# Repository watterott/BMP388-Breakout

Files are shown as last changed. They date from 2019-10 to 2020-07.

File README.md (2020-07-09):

# BMP388-Breakout
Breakout with BMP388 Digital Absolute Barometric Pressure Sensor from Bosch Sensortec.

* [Bosch BMP388](https://www.bosch-sensortec.com/bst/products/all_products/BMP388) Absolute Barometric Pressure Sensor
* Pressure Range: 300...1100hPa (+9000...-500m above/below sea level)
* On-board 3.3V voltage regulator
* SPI Interface (up to 10MHz)
* TWI/I2C Interface (address 0x76 when SDO=0 or 0x77 when SDO=1, CS=1 for I2C)
* 3.3V - 5V Power Supply and Logic Level
* Open-Source and released under the [Creative Commons Attribution Share-Alike License](https://creativecommons.org/licenses/by-sa/4.0/).
* **[Documentation on learn.watterott.com](https://learn.watterott.com)**

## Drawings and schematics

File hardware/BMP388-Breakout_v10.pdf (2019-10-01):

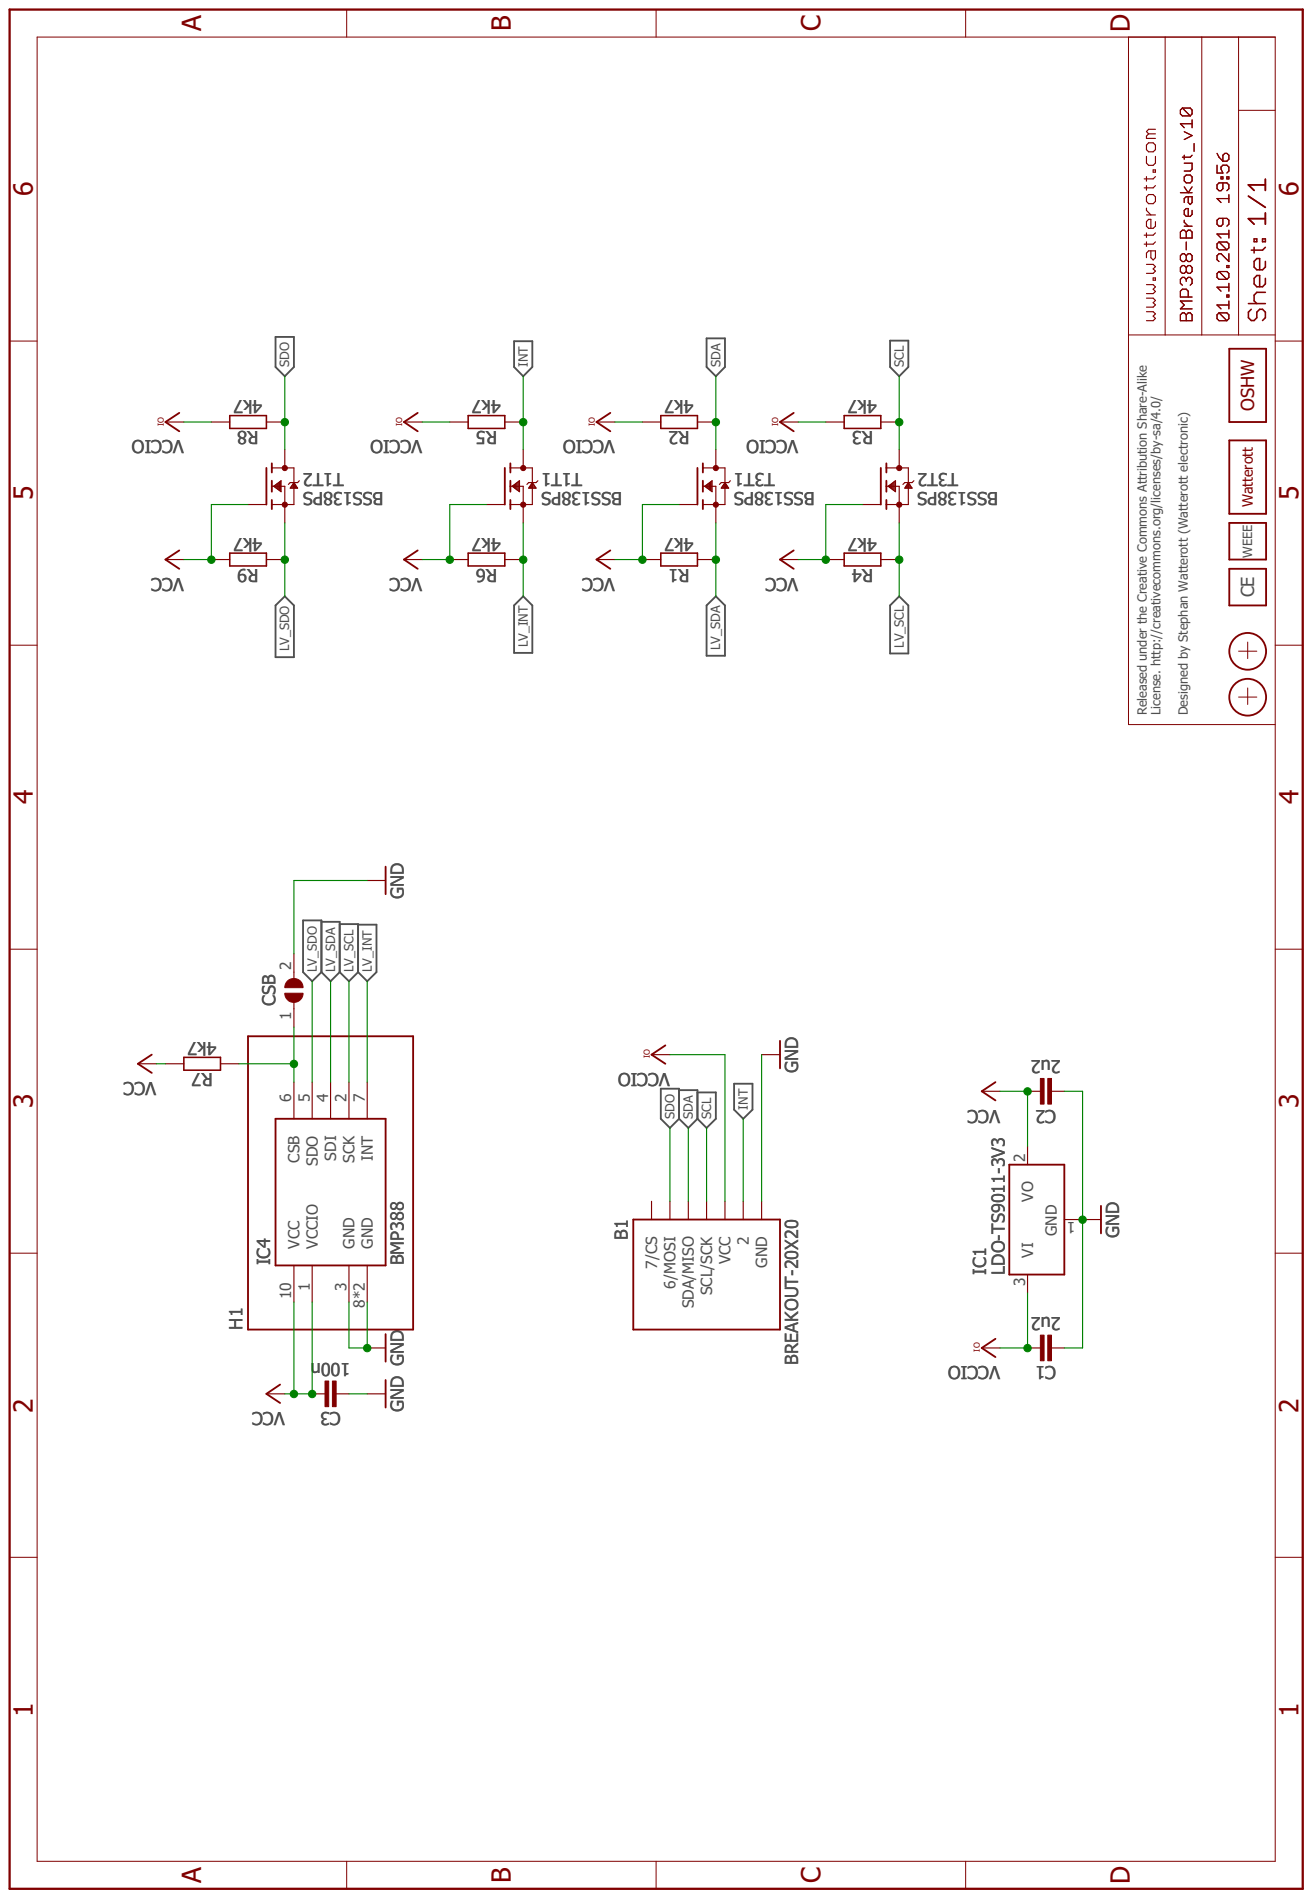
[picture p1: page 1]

Released under the Creative Commons Attribution Share-Alike

License. http://creativecommons.org/licenses/by-sa/4.0/ Designed by Stephan Watterott (Watterott electronic)

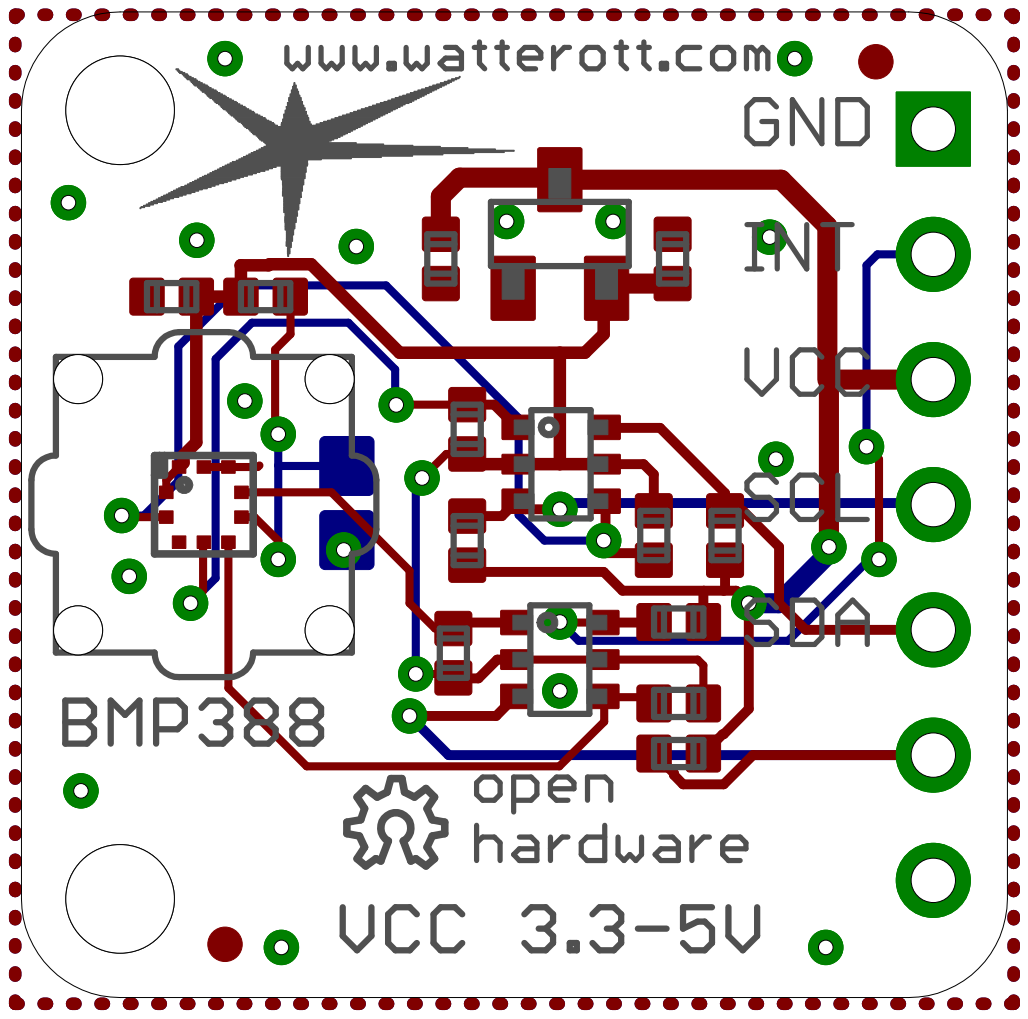
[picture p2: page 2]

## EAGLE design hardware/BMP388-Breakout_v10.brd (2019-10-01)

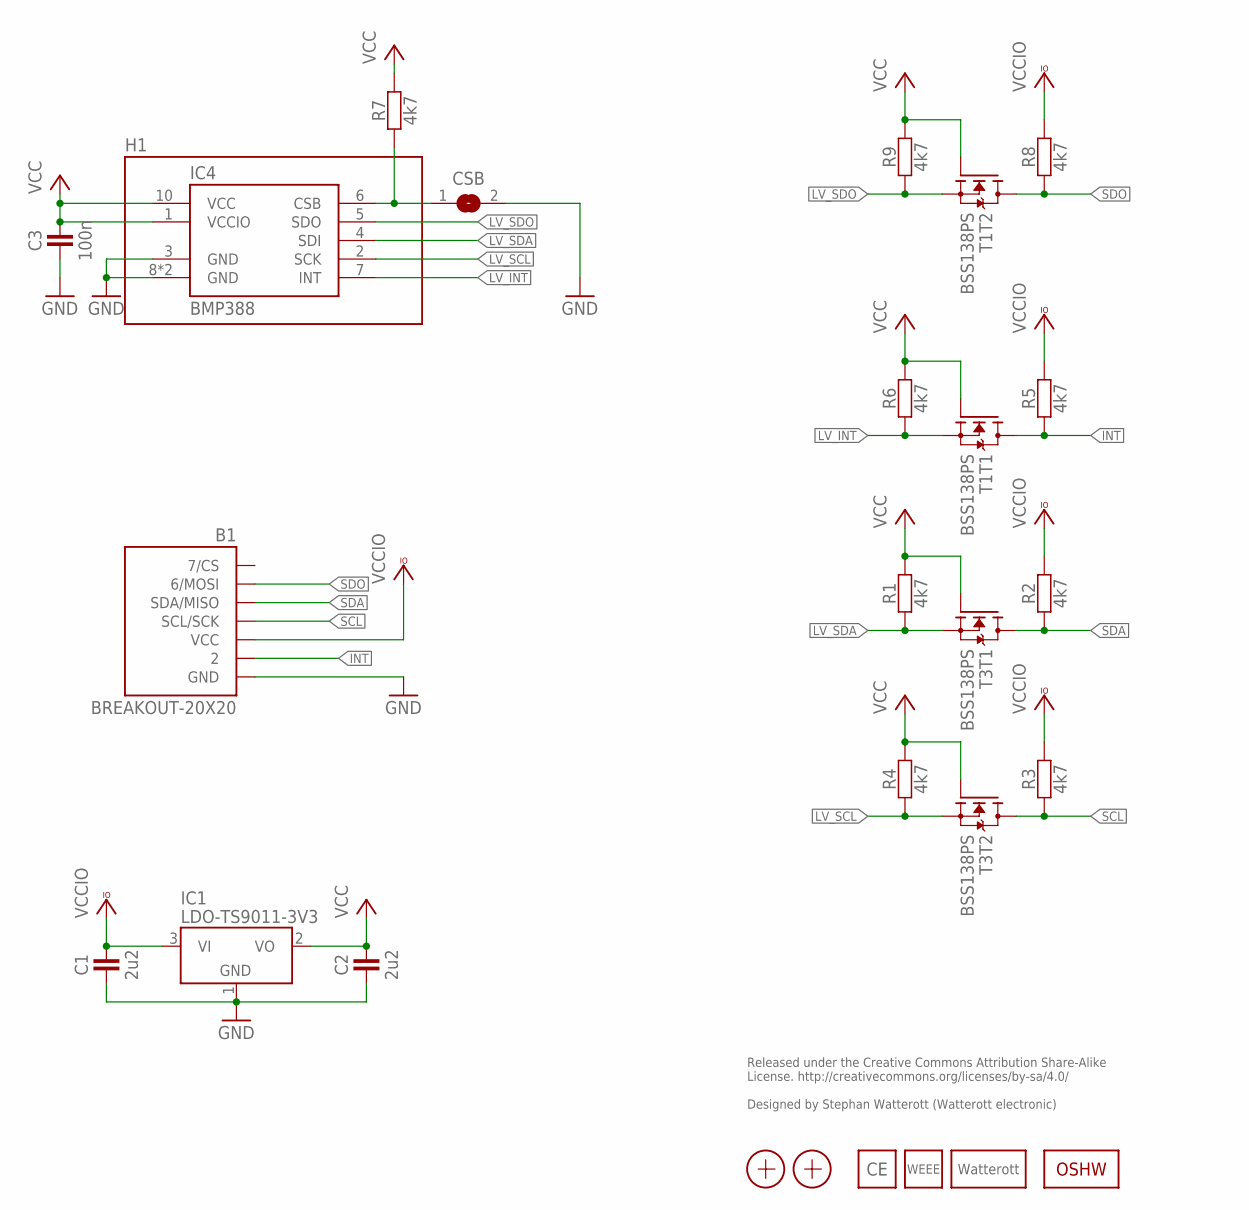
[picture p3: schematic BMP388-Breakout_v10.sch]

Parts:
B1: BREAKOUT-20X20
C1, C2: 2u2; C0402
C3: 100n; C0402
CSB: JUMPER2-0603-NC; JUMPER2-0603_NC
H1: SF2
IC1: LDO-TS9011-3V3; SOT23
IC4: BMP388
LOGO2: OSHW_LOGOX0070; OSHW_6X70
LOGO3: LOGO_WEEE-4; WEEE_4MM
LOGO4: LOGO_CE-4; CE_4MM
LOGO5: LOGO_SPARK-4; SPARK_4MM
R1, R2, R3, R4, R5, R6, R7, R8, R9: 4k7; C0402
T1, T3: BSS138PS; SOT363
X1, X2: PASSER-07; PASSER_07MM

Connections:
GND: B1.GND, C1.1, C2.1, C3.1, CSB.2, IC1.1 (GND), IC4.3 (GND), IC4.8 (GND), IC4.9 (GND)
INT: B1.2, R5.1, T1.6 (D)
LV_INT: IC4.7 (INT), R6.1, T1.1 (S)
LV_SCL: IC4.2 (SCK), R4.1, T3.4 (S)
LV_SDA: IC4.4 (SDI), R1.1, T3.1 (S)
LV_SDO: IC4.5 (SDO), R9.1, T1.4 (S)
unnamed: CSB.1, IC4.6 (CSB), R7.1
SCL: B1.SCL/SCK, R3.1, T3.3 (D)
SDA: B1.SDA/MISO, R2.1, T3.6 (D)
SDO: B1.MOSI (6/MOSI), R8.1, T1.3 (D)
VCC: C2.2, C3.2, IC1.2 (VO), IC4.1 (VCCIO), IC4.10 (VCC), R1.2, R4.2, R6.2, R7.2, R9.2, T1.2 (G), T1.5 (G), T3.2 (G), T3.5 (G)
VCCIO: B1.VCC, C1.2, IC1.3 (VI), R2.2, R3.2, R5.2, R8.2

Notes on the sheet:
Released under the Creative Commons Attribution Share-Alike License. http://creativecommons.org/licenses/by-sa/4.0/ Designed by Stephan Watterott (Watterott electronic)

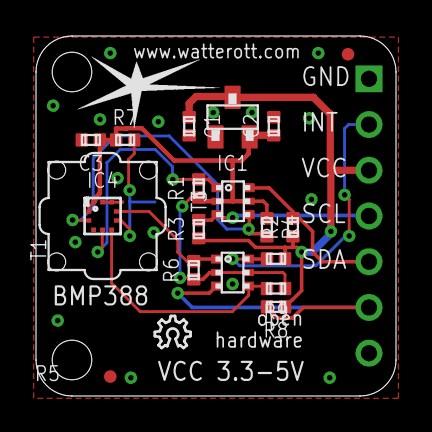
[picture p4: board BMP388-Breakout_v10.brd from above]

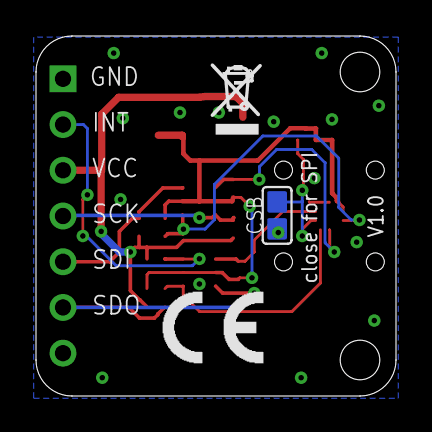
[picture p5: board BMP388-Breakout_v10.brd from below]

Board: 2 copper layers, 20.0 x 20.0 mm, 25 parts (3 on the bottom side), 12 nets.
